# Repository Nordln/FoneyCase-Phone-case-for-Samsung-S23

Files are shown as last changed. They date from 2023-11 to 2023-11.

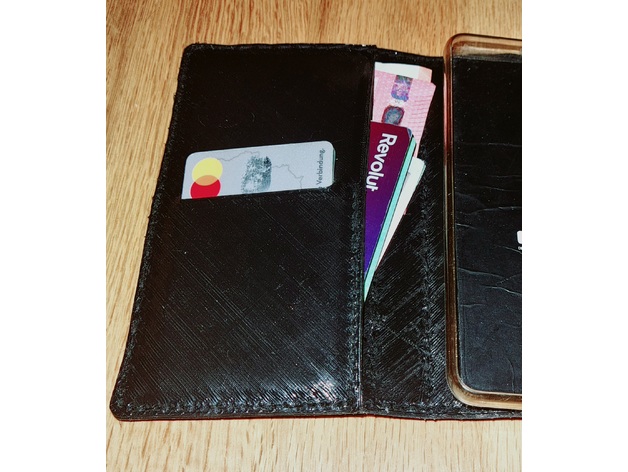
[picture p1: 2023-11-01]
20230826_231906.jpg

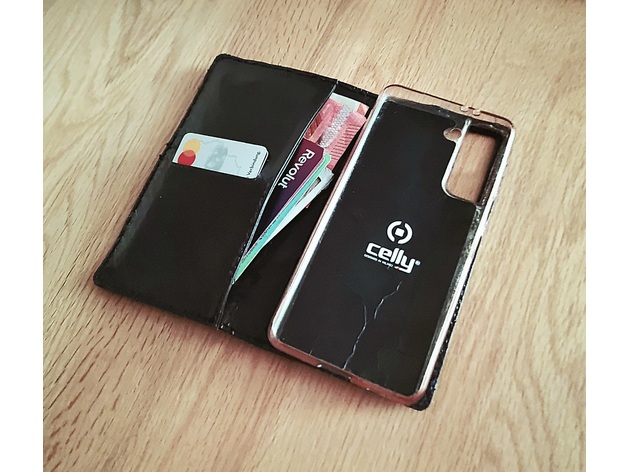
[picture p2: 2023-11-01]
20230826_232025.jpg

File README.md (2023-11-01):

# FoneyCase-Phone-case-for-Samsung-S23

A neat sew-together phone case for a Samsung S23. Note: BOSL2 scad libraries are required. Made to replace my current case and as a test of the concept.

All skin layers should be printed using flexible filament. The stiffener plate layer should either be printed in normal filament or cut from material you have laying about. This includes metal if you want to protect your cards from RFID skimming and/or spare your goodies from radiation(?). This would be at the expense of phone signal when pocketed.   

All layers are sewn together using standard thread using the aligned holes provided. I recommend a back stitch (quicker) or a hand-sewn saddle stitch with lock-stitches (slower but better if thread breaks after heavy wear). This can all be unstitched for any later mods you wish to add. The card and cash wallets should be sewn at their single edge seam first before all layers are sewn together. I did not print out the phone holder, using it instead as a guide. I opted to use the holder from an old phone case I was replacing. A spread of dots of Gorilla Glue on the surface farthest from the centre (see re clasp, below) was the best adhesive I found for attaching the holder to the case.

Layer thickness can vary - I went with 0.75mm in the end. This produced 3 layers on my stock Ender-3 using a black Ninjaflex clone material. It seems pretty sturdy. 

The strap is intended to be used as a magnetic clasp with small embedded magnets. Note that the case directly under the phone holder is split into two plates. This is so the back can be folded and used as a phone wedge on a table.  A second case magnet can be placed internally and used with the strap to keep this form stable when used. Note that this only works if the phone holder is not glued to both plate sections behind it. 

The scad file is included. Global variables are used as much as possible, should people want to customise for another phone. Due to slightly scrappy code, some ultra-fine tuning in the modules may still be needed if drastic alterations are made.

The reference S23 holder model was created by thingiverse user Icepir8, licensed under gpl.

Footnote: I originally intended to print the layers over a bed lined with leather to get the faux leather impression on the surfaces - hence 'foney'. Whilst I think this may have worked, I actually quite liked the printmarks so I did not pursue this. I also planned to use the flexible filament itself as the thread, since pulling a piece extends it to a stable thinner form about 1/4 the thickness without stretching further. I did not pursue this either, as I was low on filament and arguably, it is a bit wasteful.

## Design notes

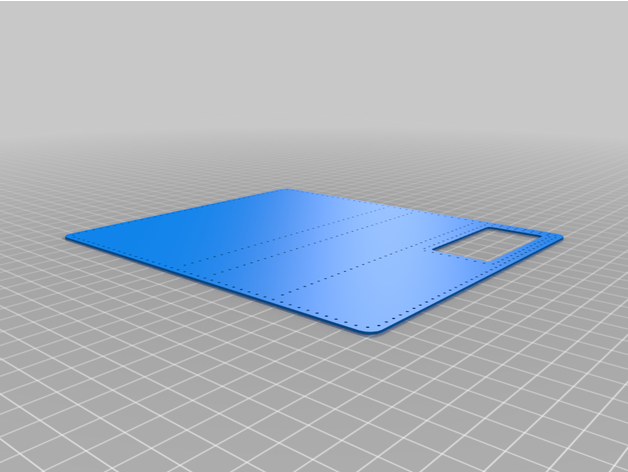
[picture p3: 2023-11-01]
outer_inner_1mm.png

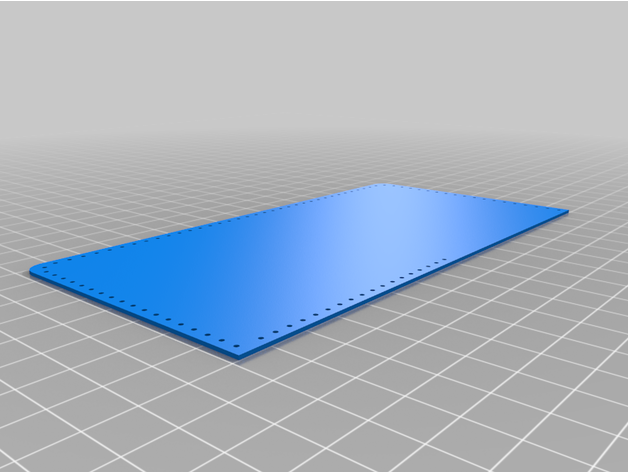
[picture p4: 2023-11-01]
note_wallet_1mm.png

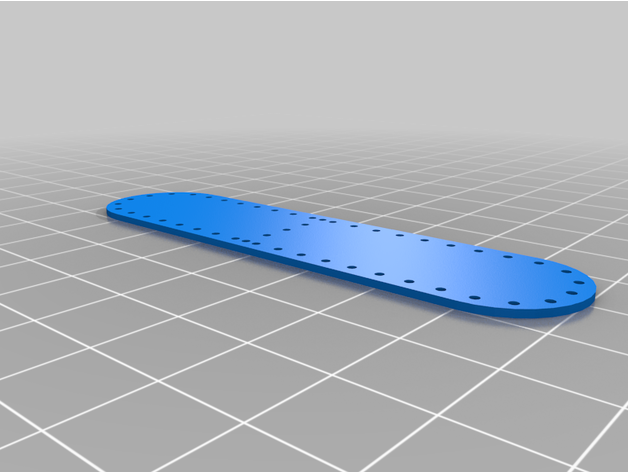
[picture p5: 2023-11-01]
strap_1mm.png

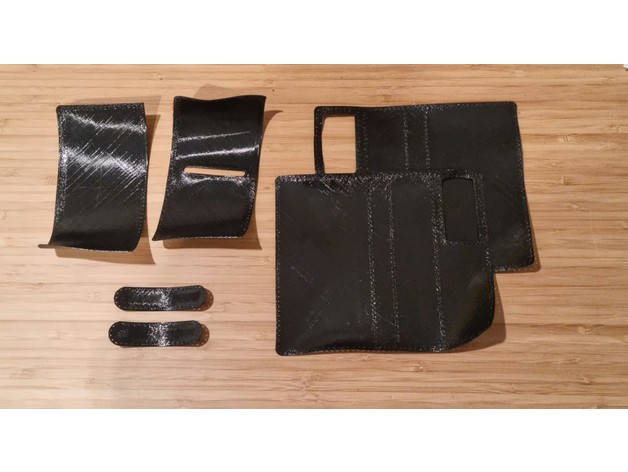
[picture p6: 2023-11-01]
20230807_221941_sm.jpg

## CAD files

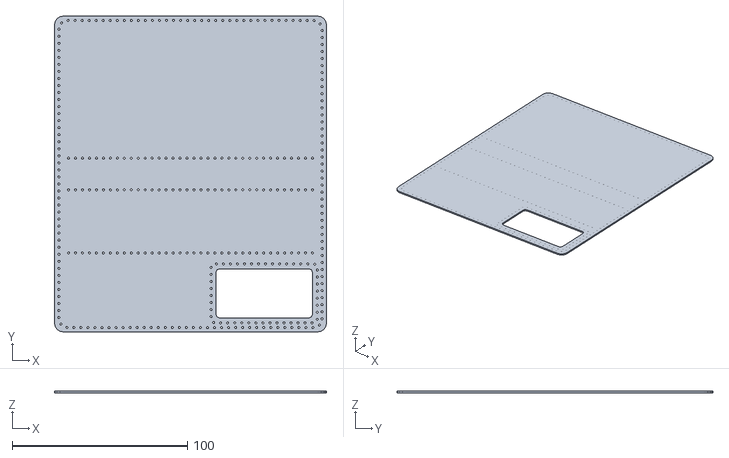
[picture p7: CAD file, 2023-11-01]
outer_inner_1mm.stl
155.0 x 180.0 x 1.00

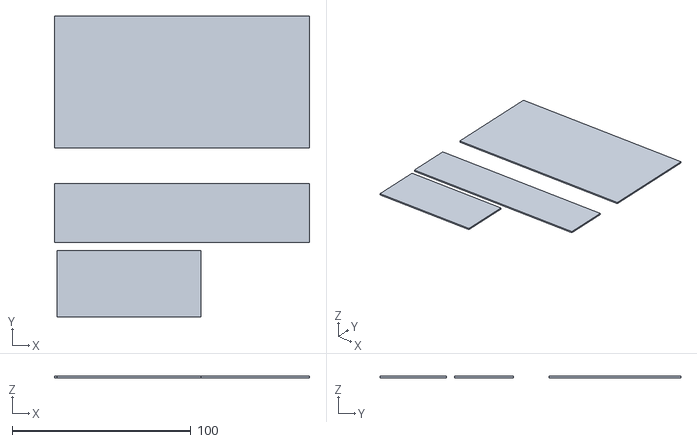
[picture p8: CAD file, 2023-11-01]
plates_1mm.stl
143.0 x 168.6 x 1.00

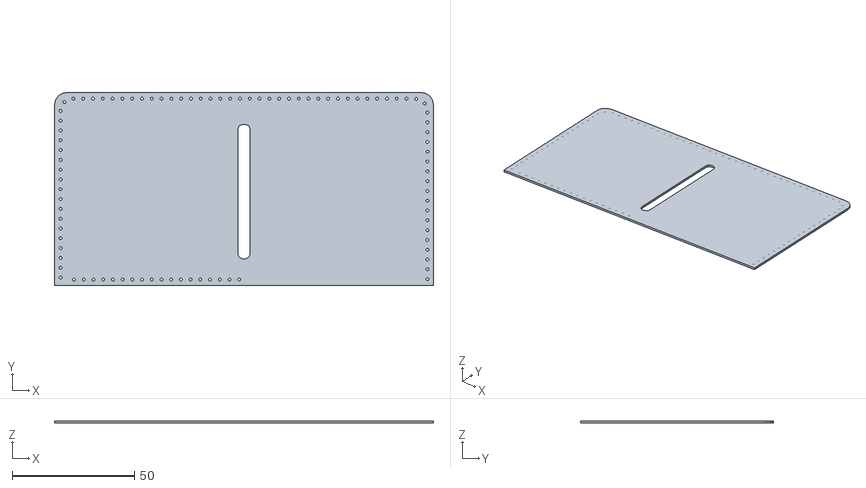
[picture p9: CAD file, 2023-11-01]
card_wallet_1mm.stl
155.0 x 78.9 x 1.00

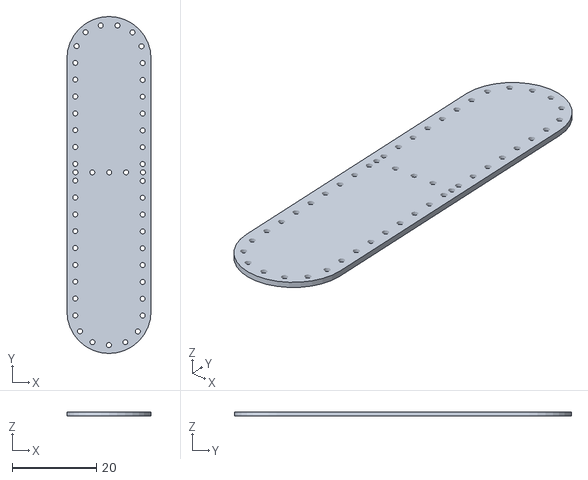
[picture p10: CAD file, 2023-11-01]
strap_1mm.stl
20.0 x 80.0 x 1.00

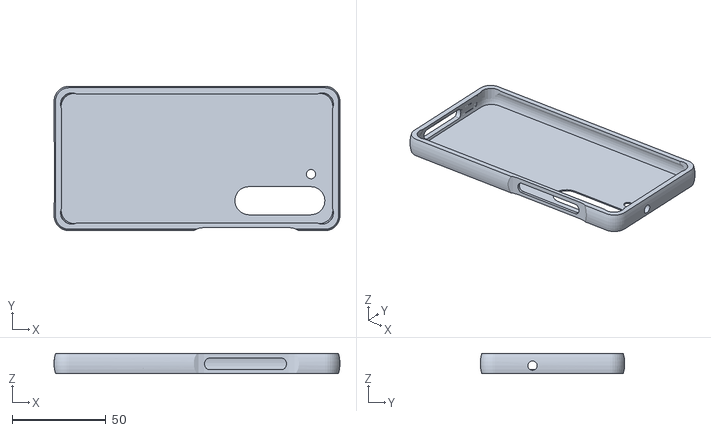
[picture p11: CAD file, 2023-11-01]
holder_1mm.stl
152.4 x 77.0 x 10.8

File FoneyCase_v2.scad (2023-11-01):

include <BOSL2/std.scad>

backplane_size_X = 155;
backplane_size_Y = 180;
hole_spacing = 4;
hole_size = 0.6;
hole_inset = 5;
core_material_inset = 12;
spine_width = 18;
spine_holes_instep = 8;

cardslotX = 5;
cardslotY = 55;

cam_cutout_size_X = 55;
cam_cutout_size_Y = 28;
cam_cutout_pos_X = 42;
cam_cutout_pos_Y = -68;

strap_size_X = 20;
strap_size_Y = 80;
strap_pos_X = -2.4;
strap_pos_Y = -backplane_size_X/2-13;
strap_hole_inset = 4;
strap_hole_spacing = 4;

layer_thickness = 1;

separation = 10;

show_phoneholder = 1;
show_strap = 1;
show_cardwallet = 1;
show_notewallet = 1;
show_midplane = 1;
show_coreplates = 1;
show_backplane = 1;

main();


// main

module main() {
    
    // phoneholder
    if(show_phoneholder==1) translate([0,-50,0 + (separation*3)]) rotate([0,0,-90]) import("S23.stl");
    
    // Magnetic stap
    if(show_strap==1) color("black") translate([0,0,0 + (separation*0.5)]) linear_extrude(height = layer_thickness) strap_panel();

    // Cardwallet
    if (show_cardwallet==1) color("green") translate([0,0,0 + (separation*4)]) linear_extrude(height = layer_thickness) cardwallet_panel();

    // Notewallet
    if (show_notewallet==1) color("orange") translate([0,0,0  + (separation*3)]) linear_extrude(height = layer_thickness) notewallet_panel();

    // Midplane
    if (show_midplane==1) color("red") translate([0,0,0 + (separation*2)]) linear_extrude(height = layer_thickness) backplane_panel();

    // Coreplates
    if (show_coreplates==1) color("pink") translate([0,0,0 + separation]) linear_extrude(height = layer_thickness) backplane_panel_core();

    // Backplane
    if (show_backplane==1) color("blue") linear_extrude(height = layer_thickness) backplane_panel();

}



// intermidates

module cardwallet_panel() {
    difference() {
        difference() {
            notewallet_panel();
            translate([0,(backplane_size_Y/4)+(spine_width/4),0]) color("yellow") cardslot();
        }
        translate([0,+spine_width*1.3,0]) cardwallet_panel_holes();
    }
}

module notewallet_panel() {
     difference() {
        intersection() {
            backplane_panel();
            translate([0,(backplane_size_Y/4)+(spine_width/2)+1.5,0]) rect([backplane_size_X,(backplane_size_Y/2)-(hole_size*2)], rounding=0);
        }
        translate([0,+spine_width*1.3,0]) cardwallet_panel_holes();
    }
}

module backplane_panel() {
    difference() {
        backplane();
        translate([cam_cutout_pos_X,cam_cutout_pos_Y,0]) camera_cutout();
        backplane_edge_holes();
        backplane_fold_holes();
    }
}

module backplane_panel_core() {
        //rect([backplane_size_X-core_material_inset,backplane_size_Y-core_material_inset], rounding=5); // core_all
        translate([0,(backplane_size_Y/4)+2,0]) rect([backplane_size_X-core_material_inset,(backplane_size_Y/2)-core_material_inset-4], rounding=0); // core_large
        translate([0,-(backplane_size_Y/8)-3.8,0]) rect([backplane_size_X-core_material_inset,(backplane_size_Y/4)-core_material_inset], rounding=0); // core_med
        translate([-(backplane_size_X-cam_cutout_size_X*1.2)/3,-(backplane_size_Y/8)*2.8-3,0]) rect([backplane_size_X-cam_cutout_size_X*1.35,(backplane_size_Y/3)-core_material_inset*1.9], rounding=0); // core_sml
}

module strap_panel(){
    difference() {
        strap();
        backplane_edge_holes();
        strap_holes();
    }
}

module backplane_edge_holes() {
   path1 = rect([backplane_size_X-hole_inset,backplane_size_Y-hole_inset], rounding=5); 
   sampled1 = resample_path(path1, spacing=hole_spacing);
   color("red")move_copies(sampled1) circle(r = hole_size, $fn=16);
   
   path2 = rect([cam_cutout_size_X*1.1,cam_cutout_size_Y*1.2], rounding=2);
   sampled2 = resample_path(path2, spacing=hole_spacing);
   color("red") translate([cam_cutout_pos_X,cam_cutout_pos_Y,0]) move_copies(sampled2) circle(r = hole_size, $fn=16);
}

module backplane_fold_holes() { 
   translate ([0,-spine_width/2,0]) {
       path = [[(-backplane_size_X /2)+spine_holes_instep,0],[0,0],[(backplane_size_X/2)-spine_holes_instep,0]];
       sampled = resample_path(path, spacing=hole_spacing);
       color("red")move_copies(sampled) circle(r = hole_size, $fn=16);
   }
   translate ([0,spine_width/2,0]) {    
       path = [[(-backplane_size_X/2)+spine_holes_instep,0],[0,0],[(backplane_size_X/2)-spine_holes_instep,0]];
       sampled = resample_path(path, spacing=hole_spacing);
       color("red")move_copies(sampled) circle(r = hole_size, $fn=16);
    }
    translate ([0,-backplane_size_Y/4,0]) {    
       path = [[(-backplane_size_X/2)+spine_holes_instep,0],[0,0],[(backplane_size_X/2)-spine_holes_instep,0]];
       sampled = resample_path(path, spacing=hole_spacing);
       color("red")move_copies(sampled) circle(r = hole_size, $fn=16);
    }
}

module cardwallet_panel_holes() { 
   translate ([0,(-spine_width/2)*1.1,0]) {
       path = [[(-backplane_size_X/2)+spine_holes_instep,0],[0,0],[0-spine_holes_instep,0]];
       sampled = resample_path(path, spacing=hole_spacing);
       color("red")move_copies(sampled) circle(r = hole_size, $fn=16);
   }

}

module strap_holes(){
   translate([strap_pos_X,strap_pos_Y,0]){
        path = rect([strap_size_X-strap_hole_inset,strap_size_Y-strap_hole_inset], rounding=7); 
        sampled = resample_path(path, spacing=strap_hole_spacing);
        color("red")move_copies(sampled) circle(r = hole_size, $fn=16);
   }
}



// primitives

module backplane() {
   rect([backplane_size_X,backplane_size_Y], rounding=5); 
}

module cardslot() {
   rect([cardslotX,cardslotY], rounding=2); 
}

module camera_cutout() {
   rect([cam_cutout_size_X,cam_cutout_size_Y], rounding=2); 
}

module strap() {
   translate([strap_pos_X,strap_pos_Y,0]) rect([strap_size_X,strap_size_Y], rounding=10); 
}

echo(version=version());
// Written by Ed Watson <mail@edwardwatson.co.uk>
//
// To the extent possible under law, the author(s) have dedicated all
// copyright and related and neighboring rights to this software to the
// public domain worldwide. This software is distributed without any
// warranty.
//
// You should have received a copy of the CC0 Public Domain
// Dedication along with this software.
// If not, see <http://creativecommons.org/publicdomain/zero/1.0/>.

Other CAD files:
note_wallet_1mm.stl
